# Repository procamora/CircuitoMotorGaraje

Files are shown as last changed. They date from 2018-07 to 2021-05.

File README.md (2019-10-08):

# CircuitoMotorGaraje
Codigo y circuito para activar el motor de una puerta de garaje

## Tareas

 - [ ] Comprobar `if (clicked) delay(1000);` con la puerta del garaje
 - [ ] Checkear que funciona bien el reset por software

La automata con los distintos estados

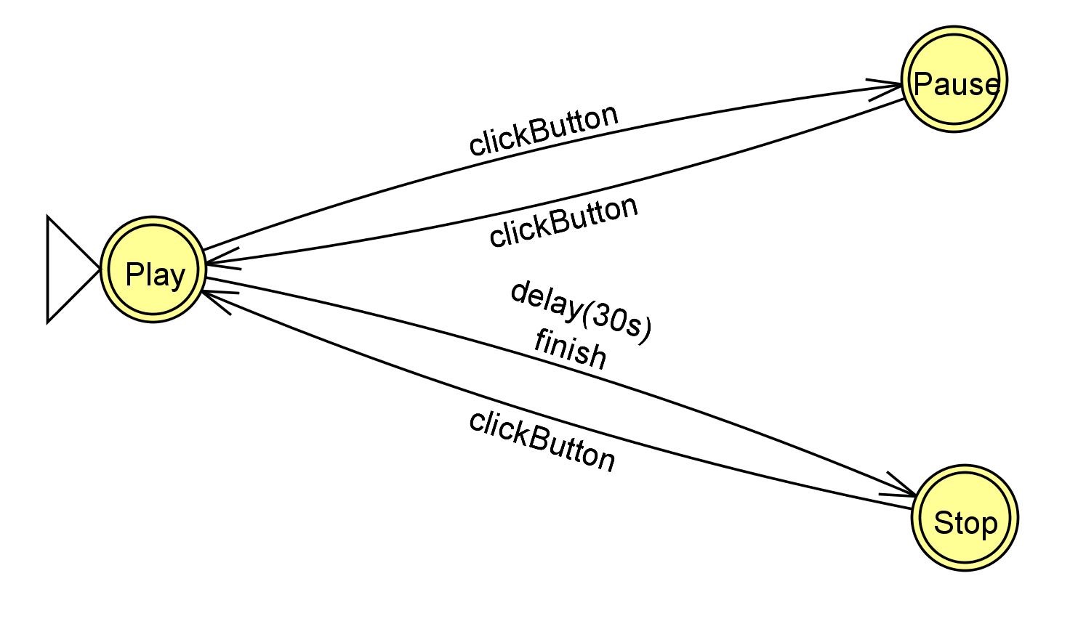
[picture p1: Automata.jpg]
Automata


El esquema de conexiones

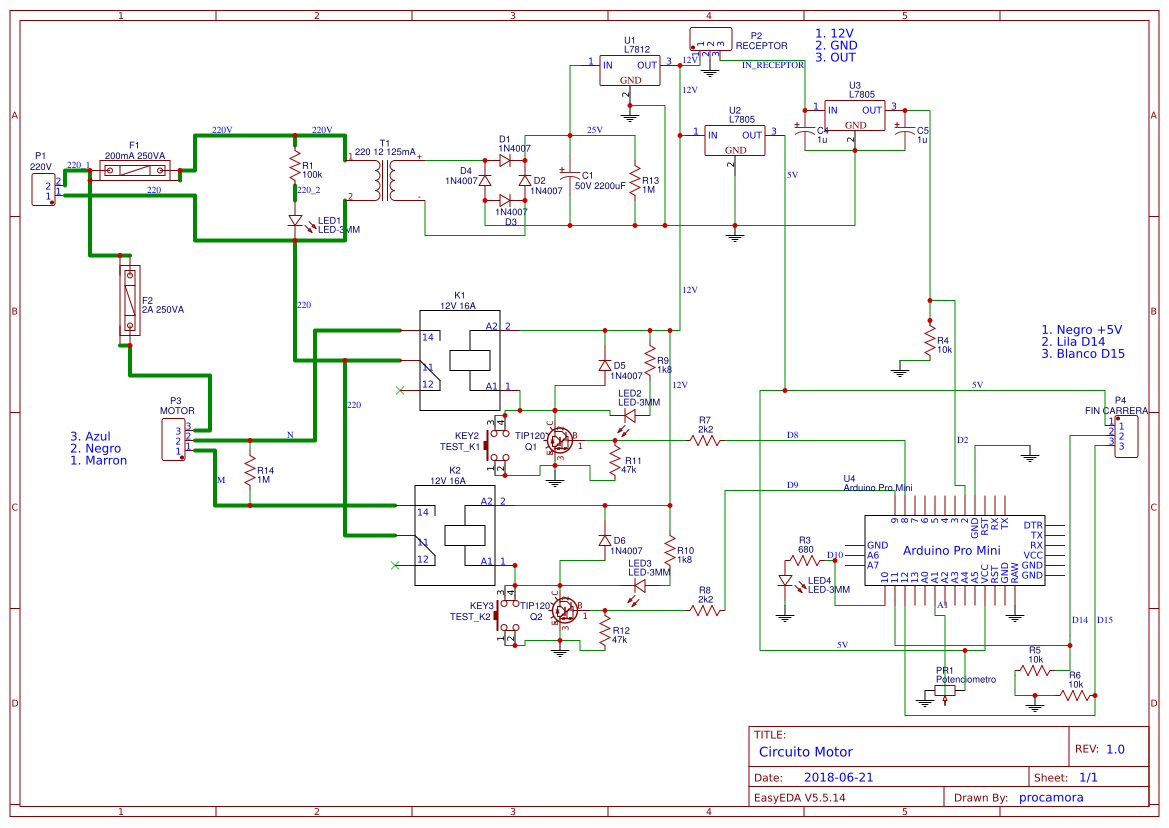
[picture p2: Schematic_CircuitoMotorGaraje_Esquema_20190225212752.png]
Eschematic


El pcb

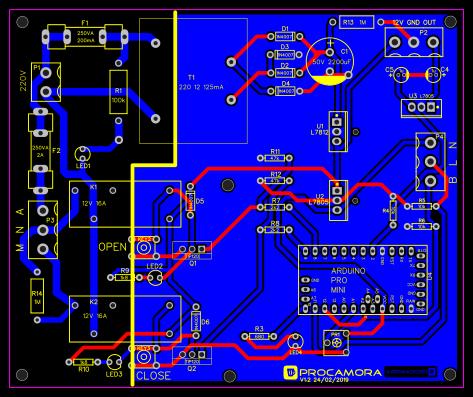
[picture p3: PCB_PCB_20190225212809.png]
PCB


# Lista de componentes

Ponerlo bonito

```csv
Designator	Footprint	Mid X	Mid Y	Ref X	Ref Y	Pad X	Pad Y	Layer	Rotation	Comment
"LED1"	"LED-3MM/2.54"	"19.3mm"	"61.83mm"	"19.3mm"	"63.2mm"	"19.3mm"	"63.1mm"	"T"	"0"	"LED-3MM"
"P1"	"WJ2EDGVC-5.08-2P"	"9.6mm"	"80.76mm"	"9.6mm"	"80.8mm"	"9.6mm"	"78.26mm"	"T"	"90"	"220V"
"D4"	"DO-35"	"72.9mm"	"78.41mm"	"76.71mm"	"78.41mm"	"76.71mm"	"78.41mm"	"T"	"180"	"1N4007"
"D3"	"DO-35"	"72.73mm"	"88.06mm"	"76.54mm"	"88.06mm"	"76.54mm"	"88.06mm"	"T"	"180"	"1N4007"
"T1"	"BV EI 305 2052"	"48.61mm"	"81.11mm"	"38.61mm"	"91.11mm"	"58.61mm"	"86.11mm"	"T"	"0"	"220 12 125mA"
"R11"	"AXIAL-0.3"	"70.11mm"	"60.7mm"	"66.3mm"	"60.7mm"	"66.3mm"	"60.7mm"	"T"	"0"	"47k"
"R12"	"AXIAL-0.3"	"70.11mm"	"54.7mm"	"66.3mm"	"54.7mm"	"66.3mm"	"54.7mm"	"T"	"0"	"47k"
"LED2"	"LED-3MM/2.54"	"38.47mm"	"29mm"	"37.1mm"	"29mm"	"37.2mm"	"29mm"	"T"	"90"	"LED-3MM"
"LED3"	"LED-3MM/2.54"	"27.67mm"	"6.7mm"	"26.3mm"	"6.7mm"	"26.4mm"	"6.7mm"	"T"	"90"	"LED-3MM"
"Q1"	"TO-220_VERTICAL"	"48.26mm"	"36.6mm"	"50.8mm"	"36.6mm"	"50.8mm"	"36.6mm"	"T"	"180"	"TIP120"
"Q2"	"TO-220_VERTICAL"	"48.26mm"	"8.7mm"	"50.8mm"	"8.7mm"	"50.8mm"	"8.7mm"	"T"	"180"	"TIP120"
"KEY2"	"KEY-6.0*6.0-2"	"35.8mm"	"36.65mm"	"35.8mm"	"36.6mm"	"39.3mm"	"34.7mm"	"T"	"0"	"TEST_K1"
"KEY3"	"KEY-6.0*6.0-2"	"35.8mm"	"7.75mm"	"35.8mm"	"7.7mm"	"39.3mm"	"5.79mm"	"T"	"0"	"TEST_K2"
"F1"	"FUSE-M205-CLIPS"	"19.95mm"	"92.8mm"	"9.5mm"	"92.8mm"	"9.5mm"	"92.8mm"	"T"	"0"	"200mA 250VA"
"C4"	"CAP-D4.0XF1.5"	"112.05mm"	"82.7mm"	"111.3mm"	"82.7mm"	"112.8mm"	"82.7mm"	"T"	"270"	"1u"
"R1"	"AXIAL-0.6"	"28.8mm"	"78.2mm"	"28.8mm"	"78.2mm"	"28.8mm"	"70.58mm"	"T"	"90"	"100k"
"P2"	"WJ2EDGVC-5.08-3P"	"106.93mm"	"91.36mm"	"106.93mm"	"91.36mm"	"101.85mm"	"91.36mm"	"T"	"0"	"RECEPTOR"
"R9"	"AXIAL-0.3"	"30.49mm"	"29.1mm"	"34.3mm"	"29.1mm"	"34.3mm"	"29.1mm"	"T"	"180"	"1k8"
"R10"	"AXIAL-0.3"	"19.49mm"	"6.7mm"	"23.3mm"	"6.7mm"	"23.3mm"	"6.7mm"	"T"	"180"	"1k8"
"D5"	"DO-35"	"47.8mm"	"49.41mm"	"47.8mm"	"45.6mm"	"47.8mm"	"45.6mm"	"T"	"90"	"1N4007"
"D6"	"DO-35"	"49.3mm"	"17.51mm"	"49.3mm"	"13.7mm"	"49.3mm"	"13.7mm"	"T"	"90"	"1N4007"
"C1"	"CAP-D12.5XF5.0"	"84.67mm"	"86.16mm"	"84.8mm"	"88.7mm"	"84.67mm"	"88.7mm"	"T"	"0"	"50V 2200uF"
"D1"	"DO-35"	"72.9mm"	"92.89mm"	"69.09mm"	"92.89mm"	"69.09mm"	"92.89mm"	"T"	"0"	"1N4007"
"D2"	"DO-35"	"72.9mm"	"83.24mm"	"69.09mm"	"83.24mm"	"69.09mm"	"83.24mm"	"T"	"0"	"1N4007"
"R13"	"AXIAL-0.5"	"91.8mm"	"96.7mm"	"91.8mm"	"96.7mm"	"98.15mm"	"96.7mm"	"T"	"180"	"1M"
"LED4"	"LED-3MM/2.54"	"75.6mm"	"12.23mm"	"75.6mm"	"13.6mm"	"75.6mm"	"13.5mm"	"T"	"0"	"LED-3MM"
"R3"	"AXIAL-0.3"	"66.01mm"	"13.5mm"	"62.2mm"	"13.5mm"	"62.2mm"	"13.5mm"	"T"	"0"	"680"
"P4"	"WJ2EDGVC-5.08-3P"	"111.3mm"	"59.7mm"	"111.3mm"	"59.7mm"	"111.3mm"	"64.78mm"	"T"	"270"	"FIN CARRERA"
"R5"	"AXIAL-0.3"	"108.97mm"	"47.93mm"	"105.16mm"	"47.93mm"	"105.16mm"	"47.93mm"	"T"	"0"	"10k"
"R6"	"AXIAL-0.3"	"108.97mm"	"42.6mm"	"105.16mm"	"42.6mm"	"105.16mm"	"42.6mm"	"T"	"0"	"10k"
"R7"	"AXIAL-0.3"	"70.11mm"	"47.7mm"	"66.3mm"	"47.7mm"	"66.3mm"	"47.7mm"	"T"	"0"	"2k2"
"R8"	"AXIAL-0.3"	"70.11mm"	"41.7mm"	"66.3mm"	"41.7mm"	"66.3mm"	"41.7mm"	"T"	"0"	"2k2"
"C5"	"CAP-D4.0XF1.5"	"103.55mm"	"82.7mm"	"104.3mm"	"82.7mm"	"102.8mm"	"82.7mm"	"T"	"90"	"1u"
"R4"	"AXIAL-0.3"	"101.4mm"	"46.79mm"	"101.4mm"	"50.6mm"	"101.4mm"	"50.6mm"	"T"	"270"	"10k"
"U5"	"ARDUINO_PRO_MICRO"	"82.73mm"	"27.49mm"	"84mm"	"28mm"	"96.7mm"	"35.11mm"	"T"	"270"	"ARDUINO_PRO_MICRO"
"U3"	"TO-220(TO-220-3)"	"108.89mm"	"74.2mm"	"111.3mm"	"74.2mm"	"111.43mm"	"74.2mm"	"T"	"270"	"L7805"
"U1"	"TO-220(TO-220-3)"	"86.5mm"	"67.69mm"	"86.5mm"	"70.1mm"	"86.5mm"	"70.22mm"	"T"	"0"	"L7812"
"U2"	"TO-220(TO-220-3)"	"86.6mm"	"49.49mm"	"86.6mm"	"51.9mm"	"86.6mm"	"52.03mm"	"T"	"0"	"L7805"
"PR1"	"RES-ADJ_EVN6X6"	"86.5mm"	"11.8mm"	"89mm"	"9.3mm"	"89mm"	"9.3mm"	"T"	"180"	"Potenciometro"
"R14"	"AXIAL-0.5"	"7.3mm"	"24.2mm"	"7.3mm"	"24.2mm"	"7.3mm"	"17.85mm"	"T"	"90"	"1M"
"K1"	"SPDT 5MM"	"29.8mm"	"48.35mm"	"45.3mm"	"54.6mm"	"42.3mm"	"52.1mm"	"T"	"270"	"12V 16A"
"K2"	"SPDT 5MM"	"29.8mm"	"17.95mm"	"45.3mm"	"24.2mm"	"42.3mm"	"21.7mm"	"T"	"270"	"12V 16A"
"F2"	"FUSE-M205-CLIPS"	"8.19mm"	"62.55mm"	"8.19mm"	"73mm"	"8.19mm"	"73mm"	"T"	"270"	"2A 250VA"
"P3"	"WJ2EDGVC-5.08-3P"	"8.8mm"	"41.7mm"	"8.8mm"	"41.7mm"	"8.8mm"	"36.62mm"	"T"	"90"	"MOTOR"
```

[pcb]: PCB_PCB_20190225212809.png
[eschematic]: Schematic_CircuitoMotorGaraje_Esquema_20190225212752.png
[automata]: Automata.jpg

https://easyeda.com/editor#id=f6a1cdd272174ffab44827535418baf6

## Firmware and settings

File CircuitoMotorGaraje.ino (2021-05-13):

/**
  @file CircuitoMotorGaraje.ino
  @brief Controlador del motor de la puerta del garaje
  @author Pablo Rocamora pablojoserocamora@gmail.com
  @date 11/06/2018
*/

#include "CircuitoMotorGaraje.h"

#define MODO_DEBUG false



/**
   Metodo para comprobar si hemos pulsado el boton, retorna true si se ha pulsado y false en caso contrario
   Guarda el estado en el que esta. Para detectarlo comprueba si llega voltaje al pin, con un voltaje >=3 and <= 5
*/
bool isClickButton() {
  bool clicked = false;
  int reading = digitalRead(CLICK_BUTTON);
  // https://www.norwegiancreations.com/2018/10/arduino-tutorial-avoiding-the-overflow-issue-when-using-millis-and-micros/
  if (reading == HIGH && (unsigned long)(millis() - times) > debounce) {
    times = millis();
    clicked = true;
  }


  ///////////////////////////////////////
  // FIXME IMPORTANTE, ESTE IF NO SE HA CHEKEADO, PROBARLO CUANDO TENGA ACCESO AL HARDWARE
  //////////////////////////////////////
  // solo esperamos si nota una pulsacion de boton
  // Puede que haya que aumentarlo un poco, probar con el mando los tiempos de espera
  if (clicked)
    delay(1000);
  //Serial.println(String(clicked));
  //despues de 1 seg volvemos a comprobar si esta pulsado, esto es para intentar evitar falsos positivos alargando el tiempo de pulsacion
  return clicked && digitalRead(CLICK_BUTTON) == HIGH;
}

/**
   Metodo para obtener el pin al que hay que aplicar voltaje para accionar el rele
*/
int getPinRelay() {
  int in = digitalRead(IS_CLOSE_DOOR);
  if (in == LOW) {
    if (MODO_DEBUG)
      Serial.println("ABRIR");

    opening = true;
    return RELAY_OPEN_DOOR;  //8
  }

  if (MODO_DEBUG)
    Serial.println("CERRAR");

  opening = false;
  return RELAY_CLOSE_DOOR; //9
}

/**
   Metodo que retorna true cuando el pin del sensor se pone a 0V indicando que llega al final del recorrido
*/
bool finCarrera(int pinRelay) {
  int pin;
  if (pinRelay == RELAY_OPEN_DOOR)
    pin = IS_OPEN_DOOR;
  else
    pin = IS_CLOSE_DOOR;

  int in = digitalRead(pin);

  if (MODO_DEBUG) {
    Serial.println(String(RELAY_OPEN_DOOR) + ": " + String(digitalRead(RELAY_OPEN_DOOR)));
    Serial.println(String(RELAY_CLOSE_DOOR) + ": " + String(digitalRead(RELAY_CLOSE_DOOR)));
    Serial.println(String(IS_CLOSE_DOOR) + ": " + String(digitalRead(IS_CLOSE_DOOR)));
    Serial.println(String(IS_OPEN_DOOR) + ": " + String(digitalRead(IS_OPEN_DOOR)));
    Serial.println(String(in == HIGH));
    Serial.println();
  }

  if (in == LOW)
    return true;
  return false;
}

/**
   Metodo para cortar el voltaje del pin que esta activando un relay, se ejecuta cuando estando
   en modo play volvemos a pulsar el boton, retorna el pin al que aplicamos voltaje
*/
/*
  int invert(int pinRelay) {
  if (MODO_DEBUG)
    Serial.println("pauso pin: " + pinRelay);

  // Si la puerta esta abriendose apagamos el rele y activamos el de cerrar
  if (opening) {
    digitalWrite(RELAY_OPEN_DOOR, LOW); //Primero apagamos para no tener los 2 cables con tension
    delay(300);
    digitalWrite(RELAY_CLOSE_DOOR, HIGH);
    opening = false;
    return RELAY_CLOSE_DOOR;
  }
  else {
    digitalWrite(RELAY_CLOSE_DOOR, LOW);
    delay(300);
    digitalWrite(RELAY_OPEN_DOOR, HIGH);
    opening = true;
    return RELAY_OPEN_DOOR;  //8

  }
  }
*/

/**
   Metodo
*/
void play() {
  unsigned long inicio = millis();
  unsigned long fin = inicio + (potentiometerValue * TIME_ACTIVE); // tiempo maximo funcionando

  int relay =  getPinRelay();
  digitalWrite(relay, HIGH);

  if (MODO_DEBUG)
    Serial.println( "inicio pin: " + String(relay));

  delay(1000);  // esperamos 1 segudo antes de la primera comprobacion para evitar falsos positivos

  while (!finCarrera(relay) && (unsigned long) millis() <= fin) {
    if (MODO_DEBUG) {
      Serial.println("play");
      Serial.println(String(millis()) + " <= " + String(fin));
    }
    //if (isClickButton())
    //  relay = invert(relay);

    delay(80);
  }
  if (MODO_DEBUG)
    Serial.println("Termina pin: " + relay);
  digitalWrite(relay, LOW);
}

/**
   Metodo que comprueba si se ha superado el valor maximo de las variables que almacenan el valor de millis(),
   cuando se supera para a ser un numero negativo. Lo comprueba con 100 seg de adelanto para evitar fallos durante
   el proceso de abrir o cerrar la puerta
*/
bool isReboot() {
  long millisOverflow = millis() + 100000;
  if (millisOverflow < 0) {
    if (MODO_DEBUG)
      Serial.println("reinicio");
    return true;
  }
  return false;
}



void setup() {
  if (MODO_DEBUG) {
    Serial.begin(9600);
    Serial.println("Inicio");
  }

  pinMode(RELAY_OPEN_DOOR, OUTPUT);
  pinMode(RELAY_CLOSE_DOOR, OUTPUT);
  pinMode(IS_OPEN_DOOR, INPUT);
  pinMode(IS_CLOSE_DOOR, INPUT);
  pinMode(CLICK_BUTTON, INPUT);
  pinMode(LED_OK, OUTPUT);
  pinMode(ANALOG_PIN, INPUT);

  digitalWrite(LED_OK, HIGH);

  long value = analogRead(ANALOG_PIN);          // realizar la lectura analógica raw
  times = 0;         //  lo inicializamos aqui porque el reset de millis es necesario que tambien lo reinizialice

  potentiometerValue = map(value, 0, 1023, 0, 100);  // convertir a porcentaje
  if (MODO_DEBUG)
    Serial.println("Tiempo maximo activo del relay: " + String(potentiometerValue * TIME_ACTIVE) + "ms");

}

void loop() {
  // si millis genera un overflow reset de millis
  if (isReboot()) {
    RESTART;
    //setup(); //ya lo hace restart
  }

  if (isClickButton()) {
    // delay(4000);
    //if (digitalRead(CLICK_BUTTON)) {
    play();
    // }
  }
  delay(10);
}

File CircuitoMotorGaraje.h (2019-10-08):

#ifndef CircuitoMotorGaraje_h
#define CircuitoMotorGaraje_h

#define IS_CLOSE_DOOR 12
#define RELAY_OPEN_DOOR 8

#define IS_OPEN_DOOR 11
#define RELAY_CLOSE_DOOR 9

#define TIME_MAX 30 //Tiempo maximo de rele activo

#define CLICK_BUTTON 2

#define LED_OK 10

#define ANALOG_PIN A1

// Multiplicamos 50 por el porcentaje del potenciometro, va desde 0ms a 50000ms
#define TIME_ACTIVE 500

// the follow variables are long's because the time, measured in miliseconds,
// will quickly become a bigger number than can be stored in an int.
unsigned long times = 0;         // the last time the output pin was toggled
#define debounce 2000   // the debounce time, increase if the output flickers

long potentiometerValue = 0; //valor que leemos del potenciometro, es un porcentaje 0-100

bool opening = false; // para saber si estamos abriendo la puerta, usado en la funcion invert

// PUEDO USAR ESTE RESET POR SOFTWARE YA QUE NO USO NINGUNA LIBRERIA QUE PUEDA FALLAR POR CULPA DEL REINICIO DE MILLIS
#define RESTART asm("jmp 0x0000") // esto parece que reinicia la funcion millis, pero no resetea el estado de los pines
#endif

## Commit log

2018-06-13 codigo inicial
    [CircuitoMotorGaraje.fzz]
2018-06-16 modificados pines y diagrama
    [CircuitoMotorGaraje.fzz]
2018-06-16 diseño en proceso
    [CircuitoMotorGaraje.fzz]
2018-07-25 codigo funcional con potenciometro
    [CircuitoMotorGaraje.fzz]
2018-08-06 cambiado atmega328p por arduino pro micro
2018-08-22 arreglo fallo al invertir movimiento
    [CircuitoMotorGaraje.ino]
2019-02-25 cambiada arduino y pcb actualizado a 2 caras
2019-10-07 eliminado invert, intento evitar bufferoverlow millis(), aumento tiempo pulsacion boton
    [CircuitoMotorGaraje.h, CircuitoMotorGaraje.ino]
2019-10-08 implementado reinicio por software si millis genera overflow a long, sin testear
2019-10-08 eliminados print
2021-05-13 try fix arduino millis overflow
    [CircuitoMotorGaraje.ino]
